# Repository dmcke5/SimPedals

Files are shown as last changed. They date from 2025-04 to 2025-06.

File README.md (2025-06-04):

# CNCDan - Sim Pedals
A laser cut, 3D printed, hall effect and load cell compatible racing simulator pedal design.

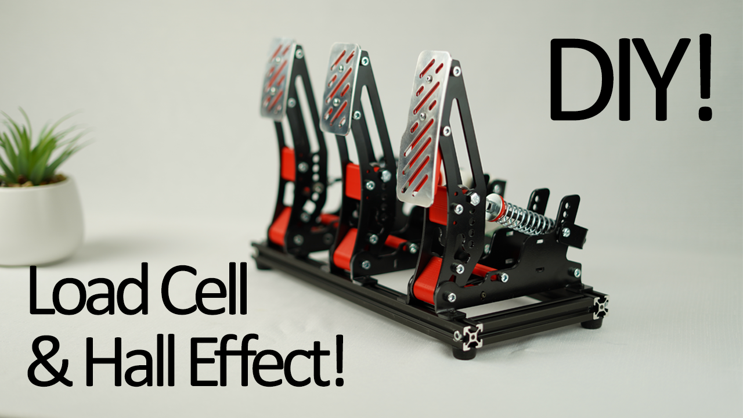
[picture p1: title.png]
Sim Pedals


This project is part of my DIY Sim racing series. The aim was to create a high quality set of sim racing pedals with no compromises, as cheaply as possible!

All of the pedal bodies are interchangeable so you can build any combination of pedals you wish. Hall effect and load cells are supported by all pedals so you can pick and choose what you feel will work best.

There are two folders that contain the parts you will need, Metal components and Printed components. The printed components are just .STL files and have quantities in their file names assuming a standard 3 pedal setup. For the metal components I have provided a STEP and DXF file for each part and a PDF with basic folding instructions for the folded parts which should be enough information for any cut service.

There are two different types of pedal plates included. Printed and metal. If you aren't using the metal version, there is no need to print the pedal mounts or the pedal form as the printed pedals incorporate the mount and the plate into one part. 

If you're planning to fold your own parts, you can just order 6x of the "3mm Pedal Base Plate" and ignore the "3mm Pedal Base Plate Mirrored" file as they are identical parts just folded the opposite direction. This will save you some money!

I've not included any software yet but I will once I integrate the pedals, shifter and wheel all into one device.

Link to video: https://youtu.be/44LWekyILmk

#### Bill of Materials

6x 625 Bearings - https://www.aliexpress.com/item/1005006600483688.html

2x 6x2 Magnets - https://www.aliexpress.com/item/1005008893908031.html

2x Hall Effect Sensor - https://www.aliexpress.com/item/1005006061649001.html

1x NA151 Load Cell 200kg - https://www.aliexpress.com/item/1005005510555008.html

1x HX711 Load Cell Amp - https://www.aliexpress.com/item/1005006851380544.html

3x M6 Female Rod End (Si6M6) - https://www.aliexpress.com/item/1005004112779993.html

3x 6x12x8 Retaining Collar - https://www.aliexpress.com/item/1005004975920947.html

2020 Extrusion (2x 370mm, 2x 130mm) - https://www.aliexpress.com/item/1005004263746376.html

4x 2020 corner brackets - https://www.aliexpress.com/item/1005007297685965.html

#### Nuts, Bolts and Washers

9x M5x50 SHCS

15x M5x40 SHCS

3x M6x40 SHCS

3x M6x130 SHCS (Minimum length, can be longer)

21x M5 Nuts

6x M5 Nyloc Nuts

6x M6 Nuts

6x M4x16 BHCS (used only for metal pedal plates)

12x M5 Washers

3x M6 Large Washers

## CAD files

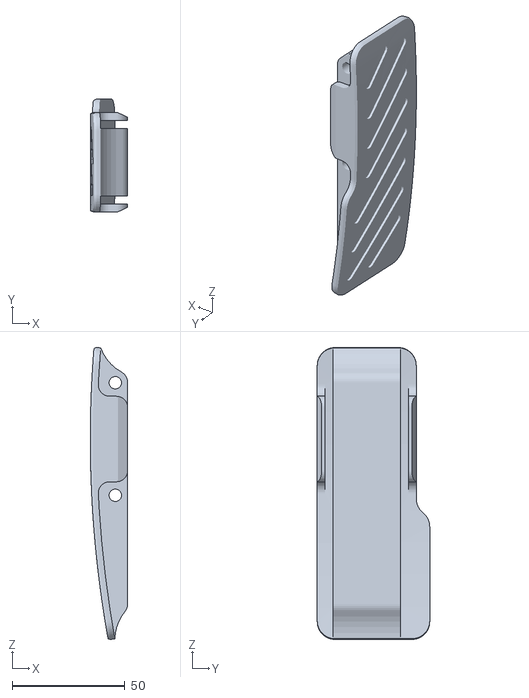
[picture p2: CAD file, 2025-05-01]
Printed Components/Fully Printed Throttle Pedal.STL
16.6 x 50.0 x 129.7

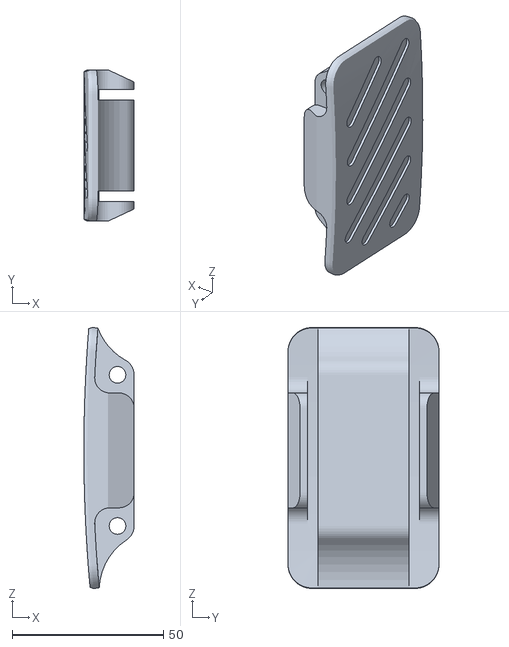
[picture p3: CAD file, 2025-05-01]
Printed Components/Fully Printed Brake Clutch Pedal.STL
16.6 x 50.0 x 86.3

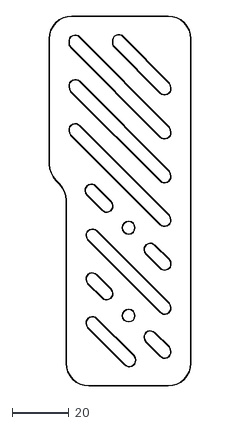
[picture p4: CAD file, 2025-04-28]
Metal Components/Aluminium Pedal Plates/2mm Throttle Pedal Plate Sheet Metal.DXF
50.0 x 130.8

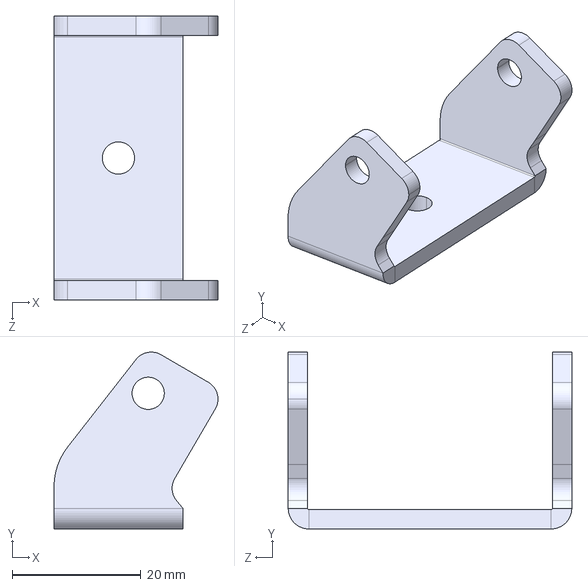
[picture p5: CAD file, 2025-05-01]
Metal Components/Steel Parts/3mm Angled Load Cell Bracket x1.STEP
25.4 x 27.4 x 44.0 mm

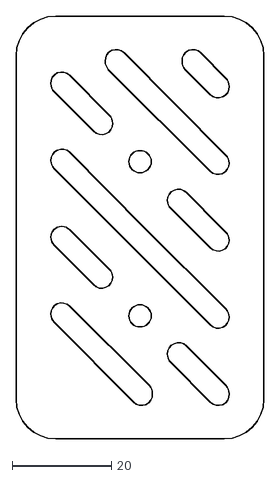
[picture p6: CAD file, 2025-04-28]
Metal Components/Aluminium Pedal Plates/2mm Brake & Clutch Pedal Plate Sheet Metal.DXF
50.0 x 85.4

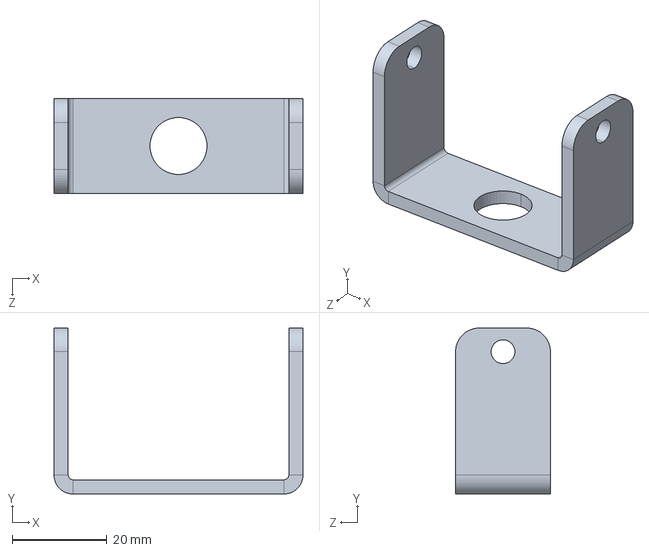
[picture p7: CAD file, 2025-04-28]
Metal Components/Steel Parts/3mm Spring Back Plate x2.STEP
52.5 x 35.0 x 20.0 mm

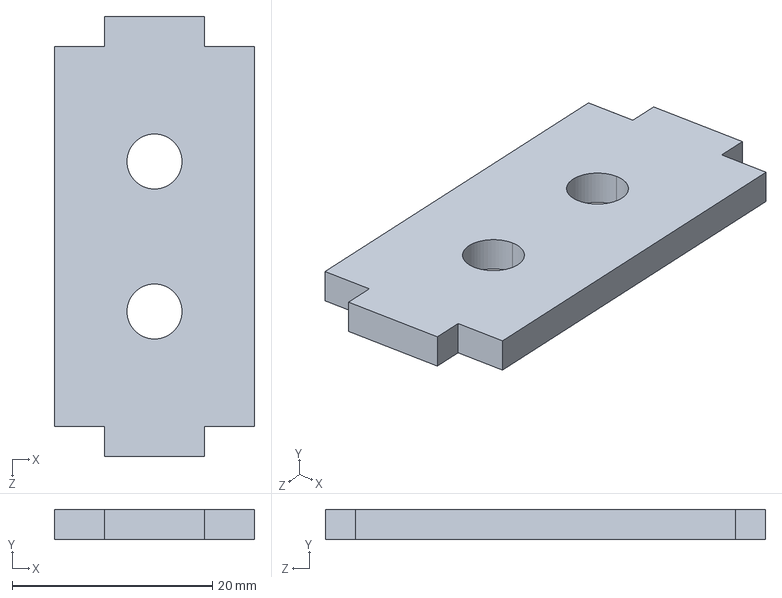
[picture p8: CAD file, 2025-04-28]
Metal Components/Steel Parts/3mm Load Cell Mounting Plate x2.STEP
20.0 x 3.00 x 44.0 mm

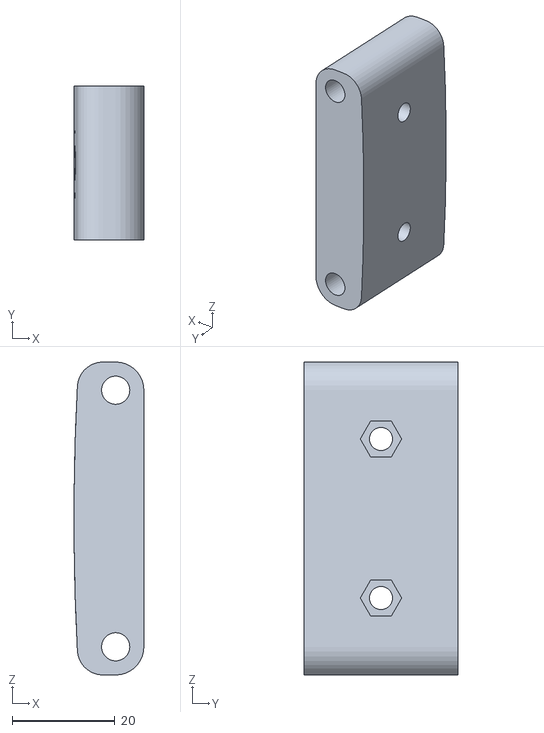
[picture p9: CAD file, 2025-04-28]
Printed Components/Pedal Mount x2.STL
13.6 x 30.0 x 61.0

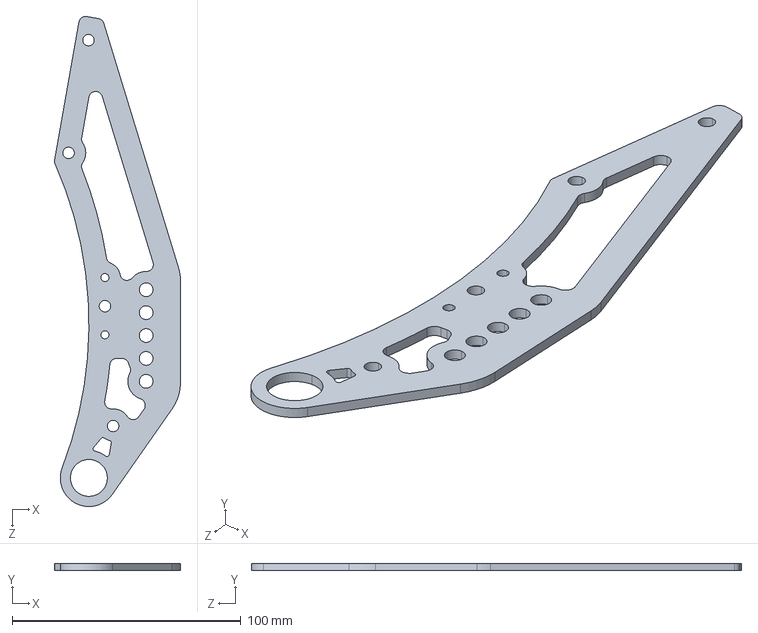
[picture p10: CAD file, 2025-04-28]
Metal Components/Steel Parts/3mm Pedal Side Plate x6.STEP
55.0 x 3.00 x 214.0 mm

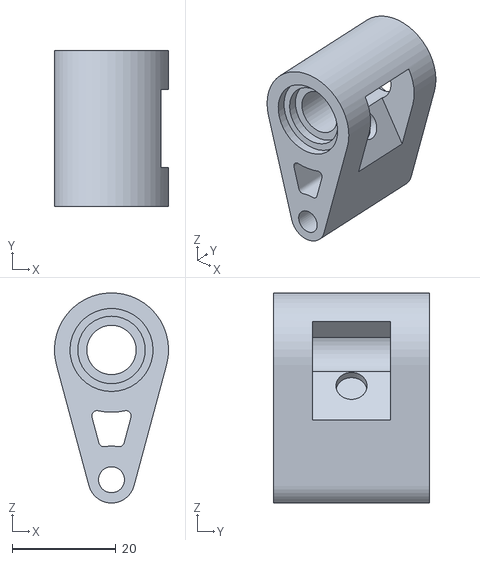
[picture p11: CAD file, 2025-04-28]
Printed Components/Pedal Bearing Mount x3.STL
22.0 x 30.0 x 40.5

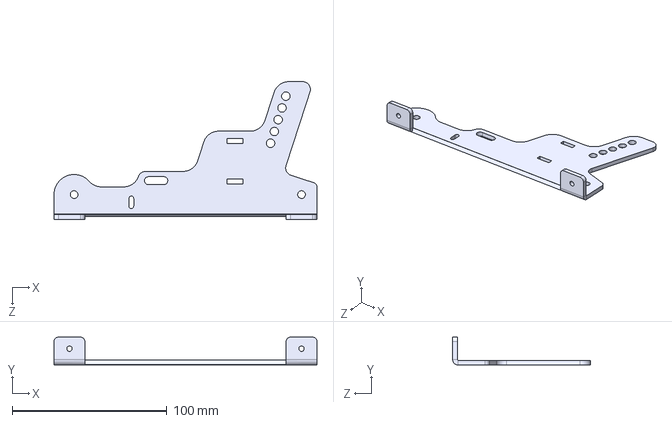
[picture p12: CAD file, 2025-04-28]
Metal Components/Steel Parts/3mm Pedal Base Plate x3.STEP
170.0 x 18.0 x 89.0 mm

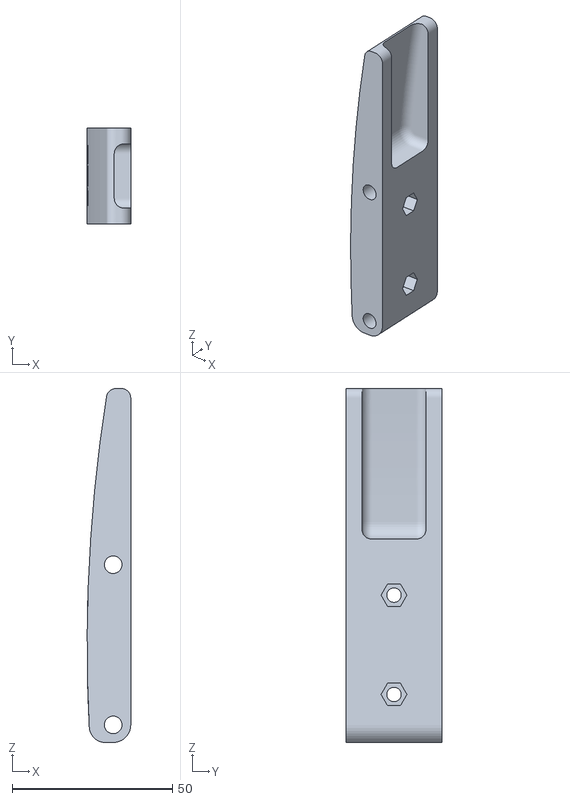
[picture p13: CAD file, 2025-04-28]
Printed Components/Pedal Mount Throttle x1.STL
13.6 x 30.0 x 110.5

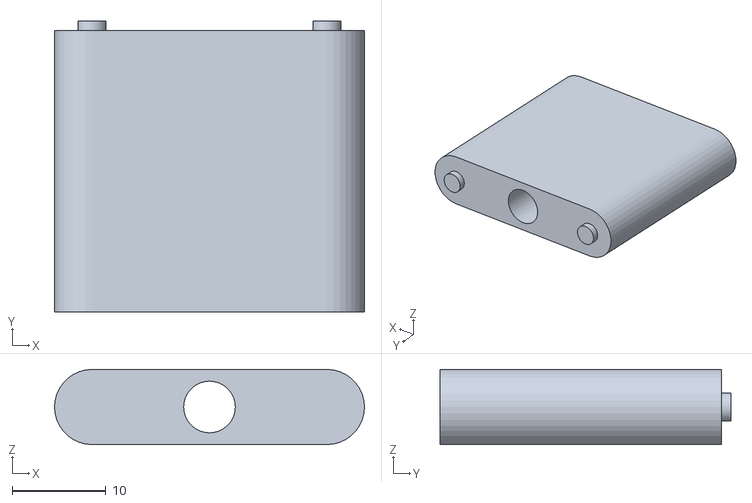
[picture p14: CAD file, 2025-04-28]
Printed Components/Pedal Spacer x3.STL
33.0 x 31.0 x 8.00

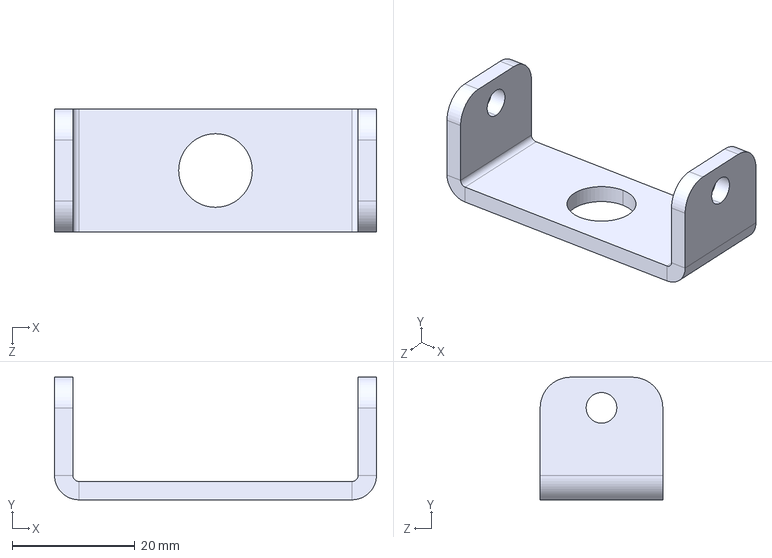
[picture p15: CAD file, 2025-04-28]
Metal Components/Steel Parts/3mm Brake Spring Back Plate x1.STEP
52.5 x 20.0 x 20.0 mm

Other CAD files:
Metal Components/Steel Parts/3mm Pedal Base Plate Mirrored x3.STEP
Printed Components/Limit Stop Tube x6.STL
Metal Components/Steel Parts/2mm Foot Plate x1.STEP
Printed Components/Foot Rest Support (Mirror pair).STL
Metal Components/Steel Parts/2mm Foot Plate x1.DXF
Metal Components/Steel Parts/3mm Angled Load Cell Bracket x1.DXF
Metal Components/Steel Parts/3mm Brake Spring Back Plate x1.DXF
Metal Components/Steel Parts/3mm Load Cell Bracket x1.DXF
Metal Components/Steel Parts/3mm Load Cell Mounting Plate x2.DXF
Metal Components/Steel Parts/3mm Pedal Base Plate Mirrored x3.DXF
Metal Components/Steel Parts/3mm Pedal Base Plate x3.DXF
Metal Components/Steel Parts/3mm Pedal Side Plate x6.DXF
Metal Components/Steel Parts/3mm Spring Back Plate x2.DXF
Printed Components/Brake pedal form (Don't print if using printed pedals).STL
Printed Components/Clevis Spacer x6.STL
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

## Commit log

2025-04-28 Added license and files
    [2mm Brake & Clutch Pedal Plate Sheet Metal.DXF, 2mm Foot Plate x1.DXF, 2mm Throttle Pedal Plate Sheet Metal.DXF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]
2025-04-28 Update BOM
2025-04-28 Updated BOM
2025-04-28 Added STEP files
    [2mm Foot Plate x1.STEP, 3mm Brake Spring Back Plate x1.STEP, 3mm Load Cell Bracket x1.STEP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]
2025-04-28 Added PDF's for cut files
2025-05-01 Updated load cell position
    [3mm Angled Load Cell Bracket x1.DXF, 3mm Angled Load Cell Bracket x1.STEP, 3mm Load Cell Bracket x1.STEP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]
2025-05-01 Added printed pedals
    [Fully Printed Brake Clutch Pedal.STL, Fully Printed Throttle Pedal.STL]
